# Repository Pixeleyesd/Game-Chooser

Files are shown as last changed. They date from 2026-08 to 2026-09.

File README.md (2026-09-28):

# Game-Chooser

Game-Chooser is a piece of hardware that chooses games for you, using random functions, with a configuration menu for you to confirm which devices you have, so it can decide for you.

## Why did I make this?

I made this to introduce me to ESP32s, as well as being a cool piece of hardware I would use in my every day life. I have consulted a few of my friends about whether they would use something like this, and 6 out of 8 of them said they would also use this. It helps with indecision when deciding which games to play, as well as taking one more decision off the end user.

## Case

Designed with OnShape

### Securing the OLED and Rotary Encoder
The Game Chooser is assembled with exclusively 2mm screws, using nuts on the back side of the OLED and the Rotary Encoder. In assembly you secure these on first, as it will be difficult to access these later.

### Securing the ESP32 to the bottom of the case

The holes under the ESP32 (on the right) will be slightly smaller than 2mm due to print tolerance, therefore allowing the 2mm screw to hold itself using the plastic of the case alone. Secure the ESP32 using the shorter M2 screws, or with nuts between a longer M2 screw and the ESP32.

### Securing the batteries

The battery will be a very tight fit, with the wire end of the AA holder pointing towards the ESP32. Slide in the battery case between the ESP32 pins that stick up, pushing it in the ESP32 direction while pushing it into the case. Once this is done you should have everything inside the case, just push the remaining wires into the case.

### Securing the back panel

The back panel screws will be slightly smaller than 2mm due to print tolerance, therefore allowing the 2mm screw to hold itself using the plastic of the case (and the back panel). Simply screw almost any M2 screw with a long enough length to grip both the back panel and the main body of the case in each of the screw holes. You will need to use reasonable force to do so, you can increase the size of the holes using a drill bit with a diameter of 2mm or less, make sure not to expand it too much otherwise the screw will not grip the plastic properly. Only expand the holes if you have to. If you have a good 3D printer this should not be necessary.

## Firmware

The firmware is written in C++.

Simply flash the .cpp file I have included in the firmware folder using PlatformIO or Arduino IDE. If using either of these, you can check platformio.ini for any of the details not explained here. The board is simply a generic ESP32 Development Board, I have included the libraries you need to install below.

### Required Libraries

igorantolic/Ai Esp32 Rotary Encoder@^1.7
adafruit/Adafruit SSD1306@^2.5.17
adafruit/Adafruit GFX Library@^1.12.6

## Assembly

#### PLEASE NOTE: there may not be enough GND and 3V3 pins for all of the components, you may need to solder a few wires together in order for all components to have GND and power.

Bill of Materials (BOM):

### My 3D printed case
Provided in .STEP format in this repo. Includes the Rotary Encoder cap, body of the case, and back panel.

### Screws
1x M2 Flat Head Screw Set, view an example [here](https://www.amazon.com/dp/B0DHZSPYHH?lv=shuf&channelId=500&plpRedirect=mhFallback)

### Rotary Encoder
1x Rotary encoder HW-040, uses 3V3

### OLED Display
1x 128x64 OLED (GM009605v4.3), uses 5V or 3.3V power, monochrome

### ESP32
1x Generic ESP32 DevKit, 5V OR 3.3V power required.

### Power Supply (AA Batteries)
2x AA Batteries

1x AA x2 Double Side Battery Holder, view an example [here](https://www.ebay.com/itm/254646729123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)

#### PLEASE NOTE: if you are using a 3V or 3.3V battery, plug the battery into the 3V3 pin and plug all components and are plugged into VIN in the diagram into the 3V3 pin instead.

This circuit requires a 5V, 3V or 3.3V power source for the device and all components to function properly. I am currently using a USB-C cable for development and AA batteries for the final circuit, however you can use any 5V, 3.3V or 3V battery. For instance, you can also use a 3V pair of AA batteries wired in series (as shown in the example) or any other power source. The choice is yours!

Please refer to the circuit diagram for assistance in assembling the circuit.

## Breadboard Collapsed Example (No battery)
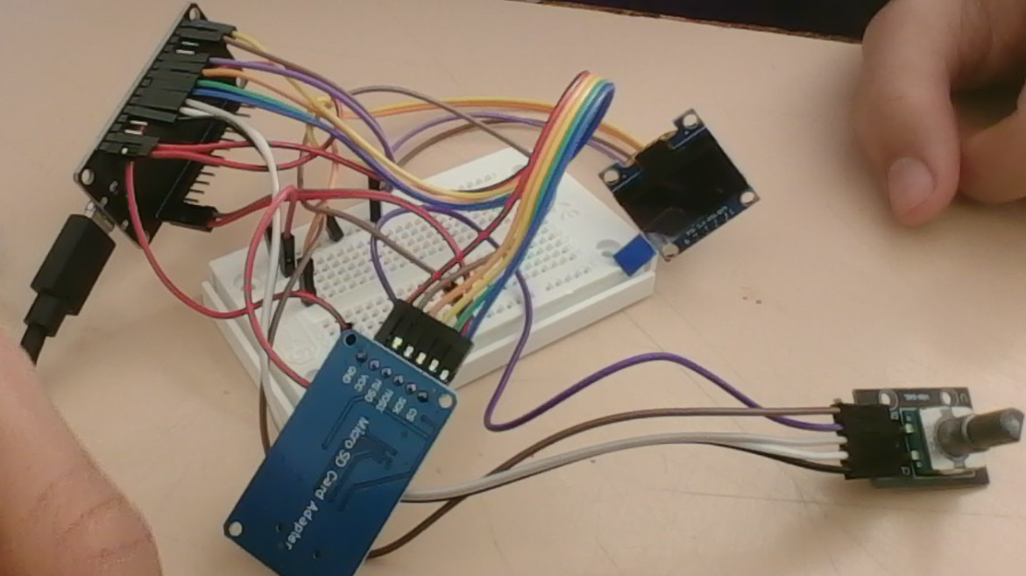
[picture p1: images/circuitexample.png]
breadboardexample


## Constructed Circuit (With battery)

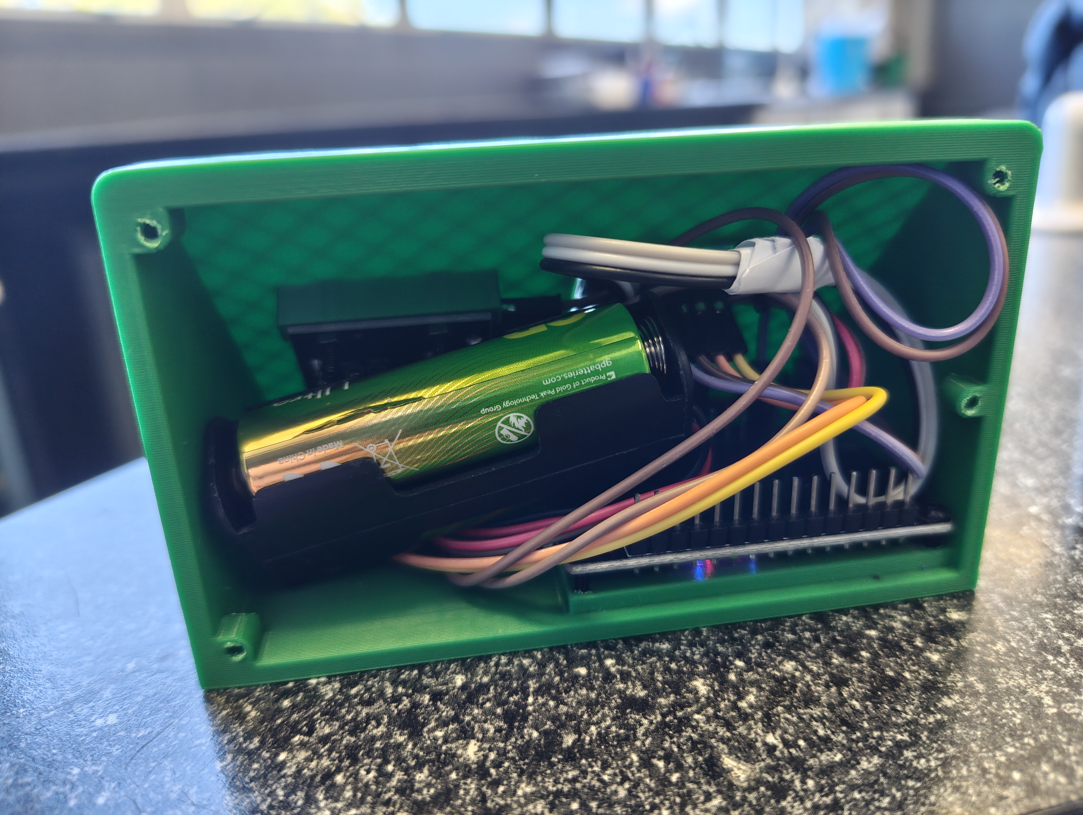
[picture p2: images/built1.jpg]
builtcircuit1


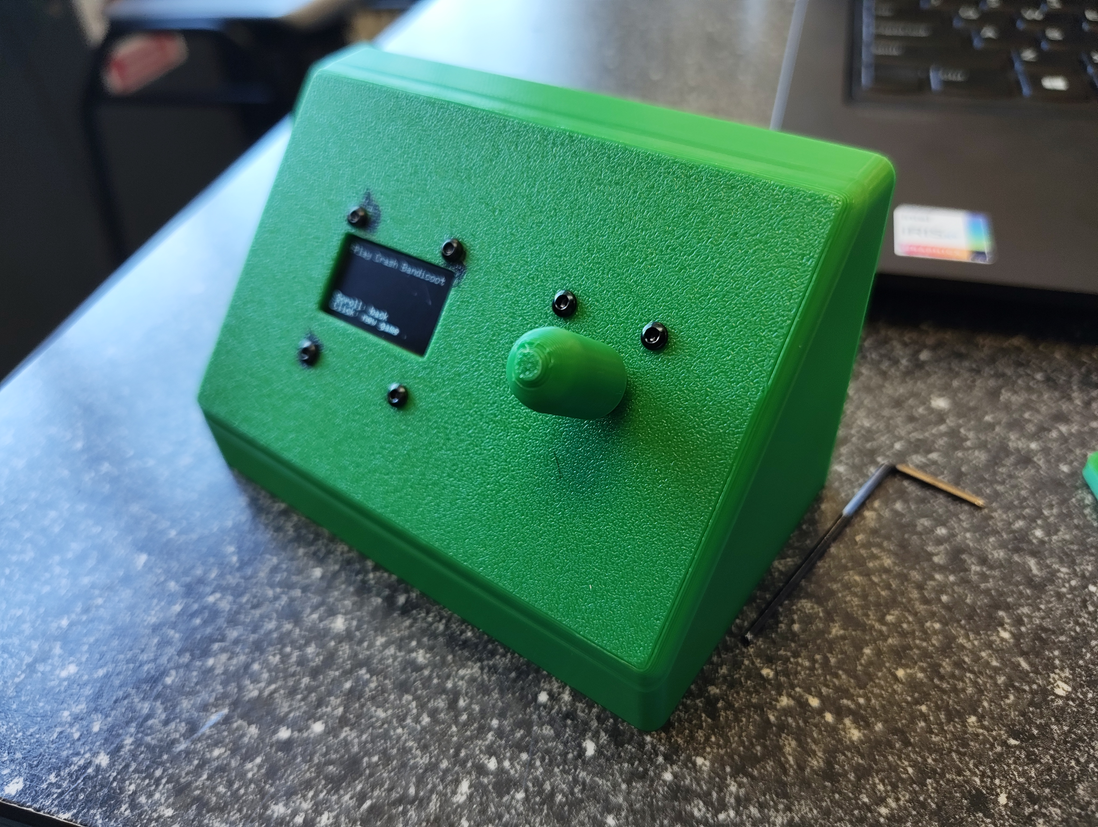
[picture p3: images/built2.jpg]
builtcircuit2


## Circuit Diagram

NOTE: I did not end up using the MicroSD Card reader.

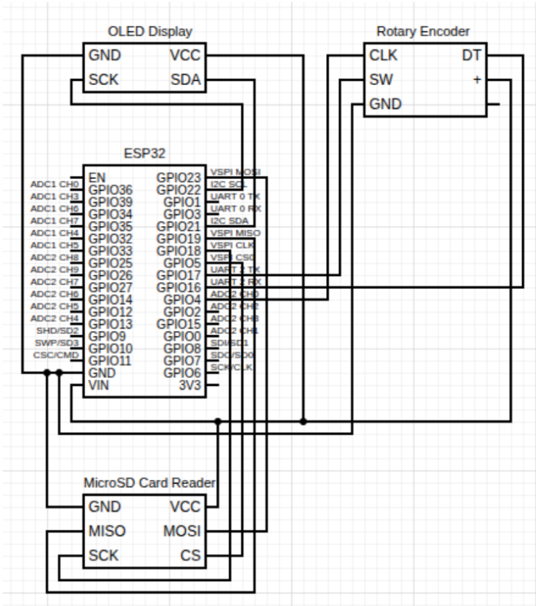
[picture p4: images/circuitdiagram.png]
circuitdiagram


## Relevant Implications
### Usability
Usability is critical because the device relies entirely on a minimal user interface. It consists of a single rotary encoder with a push button and a small 128x64 pixel monochrome OLED display. Without thoughtful interaction design, navigating nested menus on a tiny screen could quickly become frustrating.

How it is addressed in the design:

Visual Ownership Markers: Devices already added to the user's collection are dynamically tagged with an asterisk (*) in the menu rendering (renderMenu), giving instant feedback on system state.

Smart Text Wrapping: Full game titles (like "The Legend of Zelda: Tears of the Kingdom") easily exceed the display's 21-column width. The custom printWrapped() function breaks lines at word spaces rather than cutting words off mid-character.

Persistent Screen Navigation Hints: Dedicated bottom rows show contextual control prompts (e.g., "Scroll: adjust", "Click: start"), eliminating user guesswork.

Rotary Boundaries and Acceleration: Using rotaryEncoder.setBoundaries() prevents index overflow errors, while encoder acceleration ensures smooth scrolling through long lists like the 15 Nintendo models.
### Intellectual Property & Legal
Intellectual Property (IP) is a major consideration because the code explicitly hardcodes trademarked brand names (Playstation, Xbox, Nintendo), hardware model names (PS5, Switch 2, Xbox Series X), and published game titles (Final Fantasy VII, Halo, Pokémon).

How it is addressed in the design:
Personal, Non-Commercial Scope: The software operates entirely locally on an embedded micro-controller as a personal hobbyist utility. It does not distribute copyrighted assets, code, ROMs, artwork, or audio files. It only references textual names.

Fair Use / Nominal Use: Referring to brand names strictly to identify physical consoles and games in a user's personal collection falls under nominal fair use.

Zero Cloud Dependence: The device operates offline without scraping trademarked metadata or connecting to proprietary APIs, avoiding potential terms-of-service violations or network-based trademark claims.
### Functionality 
Functionality dictates whether the device performs reliably within hardware constraints. The ESP32 micro-controller has limited display area, specific pin capabilities, and power constraints, requiring careful code structure to prevent crashes, frozen screens, or inaccurate timer behavior.

How it is addressed in the design:
Non-Blocking Power Management: The sleepScreenIfIdle() function turns off the OLED display after 5 minutes of inactivity (SCREEN_TIMEOUT_MS) to save power and prevent OLED screen burn-in.

Wake-Up Input Protection: The wakeScreenIfAsleep() function intercepts the first button press or rotation after sleep to turn the display back on without accidentally triggering an unintended menu action.

True Hardware Entropy: The randomizer relies on esp_random() to seed the random generator, utilizing internal hardware noise rather than predictable analog read pins to ensure fair game selection.

Shared Memory Game Allocation: Consoles with identical libraries (e.g., PSTV/Vita, Xbox Series S/X) share array pointers (psGameLists, xboxGameLists) to optimize memory footprint.

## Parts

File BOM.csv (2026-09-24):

Item Name | Qty | Price (total) (USD) | Item link | Notes
HW-040 360 Degree Rotary Encoder Module | 1 | $0.58 | https://www.aliexpress.com/i/4001027735982.html
128X64 0.96 inch OLED Module | 1 | $1.06 | https://www.aliexpress.com/i/32805708464.html
ELEGOO ESP-32 Dev Board | 1 | $16.99 | https://www.amazon.com/dp/B0D8T53CQ5?ref=clp_cat_related_p_0&currency=USD | This is a 3 pack of the correct ESP32, I couldn't find them in single packs.
AA x2 Double Side Battery Holder | 1 | $3.40 | https://www.ebay.com/itm/254646729123?chn=ps&var=554695432330&google_free_listing_action=view_item | This is for people who want a similar battery setup to mine
AA Batteries x2 | 1 | $4.25 | https://www.amazon.com/MAX-Alkaline-Batteries-Pack-Battery/dp/B00000DM99
M2 Hex Flat Head Screw Set | 1 | $15.01 | https://www.amazon.com/dp/B0DHZSPYHH?lv=shuf&channelId=500&plpRedirect=mhFallback | This is a set of the correct type of screws.
Total Price (USD): | $41.29

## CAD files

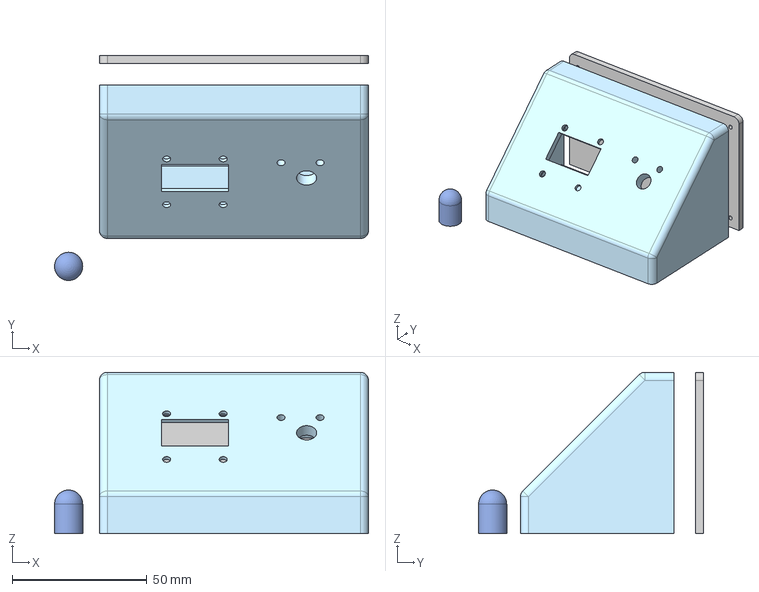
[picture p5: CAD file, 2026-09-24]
CAD/CAD.step
116.7 x 83.6 x 60.0 mm

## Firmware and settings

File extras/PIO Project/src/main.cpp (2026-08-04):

#include <Arduino.h>
#include <AiEsp32RotaryEncoder.h>
#include <Wire.h>
#include <Adafruit_GFX.h>
#include <Adafruit_SSD1306.h>

#define ROTARY_ENCODER_A_PIN 4
#define ROTARY_ENCODER_B_PIN 16
#define ROTARY_ENCODER_BUTTON_PIN 17
#define ROTARY_ENCODER_VCC_PIN -1
#define ROTARY_ENCODER_STEPS 4
#define POWER_LED_PIN 2

// GM009605 0.96" oled, ssd1306 driver, 128x64
#define OLED_SDA_PIN 21
#define OLED_SCK_PIN 22
#define OLED_WIDTH 128
#define OLED_HEIGHT 64
#define OLED_RESET -1
#define OLED_I2C_ADDR 0x3C

AiEsp32RotaryEncoder rotaryEncoder = AiEsp32RotaryEncoder(
  ROTARY_ENCODER_A_PIN, ROTARY_ENCODER_B_PIN,
  ROTARY_ENCODER_BUTTON_PIN, ROTARY_ENCODER_VCC_PIN,
  ROTARY_ENCODER_STEPS
);

Adafruit_SSD1306 display(OLED_WIDTH, OLED_HEIGHT, &Wire, OLED_RESET);

// 128px wide / 6px per char = 21 cols. 64px tall / 8px per char = 8 rows
const int LCD_COLS = 21;
const int LCD_ROWS = 8;
const int CHAR_W = 6;
const int CHAR_H = 8;

// screen auto off after being idle for this long, to save power
const unsigned long SCREEN_TIMEOUT_MS = 5UL * 60UL * 1000UL; // 5 min
unsigned long lastActivityTime = 0;
bool screenAsleep = false;

void IRAM_ATTR readEncoderISR() { rotaryEncoder.readEncoder_ISR(); }
void IRAM_ATTR readButtonISR()  { rotaryEncoder.readButton_ISR(); }

enum Category { CAT_PLAYSTATION, CAT_XBOX, CAT_NINTENDO, CAT_COMPUTER, CAT_COUNT };

const int PS_COUNT = 8;
const char* psModels[PS_COUNT] = { "PSTV", "PS Vita", "PSP", "PS1", "PS2", "PS3", "PS4", "PS5" };
bool psOwned[PS_COUNT] = { false };

const int XBOX_COUNT = 6;
const char* xboxModels[XBOX_COUNT] = { "OG Xbox", "Xbox 360", "Xbox One S", "Xbox One X", "Xbox Series S", "Xbox Series X" };
bool xboxOwned[XBOX_COUNT] = { false };

const int NINTENDO_COUNT = 15;
const char* nintendoModels[NINTENDO_COUNT] = {
  "NES", "SNES", "N64", "GameCube", "Wii", "Wii U", "Switch", "Switch 2",
  "Game Boy", "Game Boy Color", "GBA", "GBA SP", "DS", "3DS", "Virtual Boy"
};
bool nintendoOwned[NINTENDO_COUNT] = { false };

bool computerOwned = false;

// each console gets its own game list instead of sharing one per brand.
// consoles that genuinely share the exact same library in real life
// (PSTV/Vita, Xbox One S/X, Series S/X) just point at the same array

const int GAMES_PER_MODEL = 8;

const char* nesGames[GAMES_PER_MODEL] = {
  "Super Mario Bros.", "The Legend of Zelda", "Metroid", "Mega Man 2",
  "Duck Hunt", "Castlevania", "Kirby's Adventure", "Contra"
};

const char* snesGames[GAMES_PER_MODEL] = {
  "Super Mario World", "The Legend of Zelda: A Link to the Past", "Super Metroid", "Donkey Kong Country",
  "Chrono Trigger", "Super Mario Kart", "Star Fox", "EarthBound"
};

const char* n64Games[GAMES_PER_MODEL] = {
  "Super Mario 64", "The Legend of Zelda: Ocarina of Time", "GoldenEye 007", "Mario Kart 64",
  "Banjo-Kazooie", "Super Smash Bros.", "Star Fox 64", "Paper Mario"
};

const char* gamecubeGames[GAMES_PER_MODEL] = {
  "Super Mario Sunshine", "The Legend of Zelda: The Wind Waker", "Metroid Prime", "Super Smash Bros. Melee",
  "Animal Crossing", "Luigi's Mansion", "Mario Kart: Double Dash!!", "Pikmin"
};

const char* wiiGames[GAMES_PER_MODEL] = {
  "Wii Sports", "Super Mario Galaxy", "The Legend of Zelda: Skyward Sword", "Mario Kart Wii",
  "Super Smash Bros. Brawl", "Xenoblade Chronicles", "Donkey Kong Country Returns", "Metroid Prime 3: Corruption"
};

const char* wiiUGames[GAMES_PER_MODEL] = {
  "Super Mario 3D World", "Mario Kart 8", "Super Smash Bros. for Wii U", "The Legend of Zelda: Breath of the Wild",
  "Bayonetta 2", "Splatoon", "Pikmin 3", "Donkey Kong Country: Tropical Freeze"
};

const char* switchGames[GAMES_PER_MODEL] = {
  "The Legend of Zelda: Tears of the Kingdom", "Super Mario Odyssey", "Super Smash Bros. Ultimate", "Animal Crossing: New Horizons",
  "Splatoon 3", "Super Mario Bros. Wonder", "Metroid Dread", "Pikmin 4"
};

const char* switch2Games[GAMES_PER_MODEL] = {
  "Mario Kart World", "Donkey Kong Bananza", "The Duskbloods", "Splatoon Raiders",
  "Star Fox", "Metroid Prime 4: Beyond", "Fire Emblem: Fortune's Weave", "Pokemon Pokopia"
};

const char* gameboyGames[GAMES_PER_MODEL] = {
  "Pokemon Red and Blue", "The Legend of Zelda: Link's Awakening", "Super Mario Land", "Tetris",
  "Kirby's Dream Land", "Metroid II: Return of Samus", "Donkey Kong", "Wario Land: Super Mario Land 3"
};

const char* gbcGames[GAMES_PER_MODEL] = {
  "Pokemon Gold and Silver", "The Legend of Zelda: Oracle of Seasons", "Super Mario Bros. Deluxe", "Wario Land 3",
  "Pokemon Crystal", "Donkey Kong Country", "Link's Awakening DX", "Pokemon Trading Card Game"
};

const char* gbaGames[GAMES_PER_MODEL] = {
  "Pokemon Ruby and Sapphire", "The Legend of Zelda: The Minish Cap", "Metroid Fusion", "Fire Emblem",
  "Mario Kart: Super Circuit", "Golden Sun", "Metroid: Zero Mission", "Advance Wars"
};

const char* dsGames[GAMES_PER_MODEL] = {
  "New Super Mario Bros.", "Pokemon Diamond and Pearl", "The Legend of Zelda: Phantom Hourglass", "Animal Crossing: Wild World",
  "Mario Kart DS", "Nintendogs", "Professor Layton and the Curious Village", "Kirby: Canvas Curse"
};

const char* threeDSGames[GAMES_PER_MODEL] = {
  "Pokemon X and Y", "The Legend of Zelda: Ocarina of Time 3D", "Super Mario 3D Land", "Animal Crossing: New Leaf",
  "Fire Emblem Awakening", "Luigi's Mansion: Dark Moon", "Kirby: Triple Deluxe", "Mario Kart 7"
};

const char* virtualBoyGames[GAMES_PER_MODEL] = {
  "Mario's Tennis", "Red Alarm", "Galactic Pinball", "Teleroboxer",
  "Virtual Boy Wario Land", "Virtual Fishing", "3D Tetris", "Panic Bomber"
};

// pstv and vita run the same library, so pstv just points at this array too
const char* vitaGames[GAMES_PER_MODEL] = {
  "Persona 4 Golden", "Uncharted: Golden Abyss", "Gravity Rush", "Tearaway",
  "Killzone: Mercenary", "WipEout 2048", "Rayman Legends", "Danganronpa: Trigger Happy Havoc"
};

const char* pspGames[GAMES_PER_MODEL] = {
  "God of War: Chains of Olympus", "Grand Theft Auto: Liberty City Stories", "Crisis Core: Final Fantasy VII", "Patapon",
  "LocoRoco", "Monster Hunter Freedom Unite", "Daxter", "Lumines"
};

const char* ps1Games[GAMES_PER_MODEL] = {
  "Final Fantasy VII", "Metal Gear Solid", "Crash Bandicoot", "Resident Evil 2",
  "Gran Turismo", "Tekken 3", "Castlevania: Symphony of the Night", "Spyro the Dragon"
};

const char* ps2Games[GAMES_PER_MODEL] = {
  "Shadow of the Colossus", "God of War", "Grand Theft Auto: San Andreas", "Metal Gear Solid 2: Sons of Liberty",
  "Final Fantasy X", "Kingdom Hearts", "Ratchet & Clank", "Devil May Cry"
};

const char* ps3Games[GAMES_PER_MODEL] = {
  "The Last of Us", "Uncharted 2: Among Thieves", "God of War III", "Metal Gear Solid 4: Guns of the Patriots",
  "Demon's Souls", "Journey", "LittleBigPlanet", "Heavy Rain"
};

const char* ps4Games[GAMES_PER_MODEL] = {
  "Bloodborne", "Horizon Zero Dawn", "God of War", "Spider-Man",
  "Uncharted 4: A Thief's End", "Ghost of Tsushima", "Persona 5", "Death Stranding"
};

const char* ps5Games[GAMES_PER_MODEL] = {
  "Spider-Man 2", "God of War Ragnarok", "Ratchet & Clank: Rift Apart", "Returnal",
  "Gran Turismo 7", "Final Fantasy VII Rebirth", "Astro Bot", "Stellar Blade"
};

const char* ogXboxGames[GAMES_PER_MODEL] = {
  "Halo: Combat Evolved", "Fable", "Ninja Gaiden", "Jade Empire",
  "Halo 2", "Star Wars: Knights of the Old Republic", "Conker's Bad Fur Day", "Project Gotham Racing"
};

const char* xbox360Games[GAMES_PER_MODEL] = {
  "Halo 3", "Gears of War", "Mass Effect 2", "Fable II",
  "Forza Motorsport 4", "Red Dead Redemption", "Halo: Reach", "Left 4 Dead"
};

// one s and one x run the same games, no exclusives between the two
const char* xboxOneGames[GAMES_PER_MODEL] = {
  "Halo 5: Guardians", "Forza Horizon 3", "Gears of War 4", "Sea of Thieves",
  "Ori and the Blind Forest", "Cuphead", "Sunset Overdrive", "Quantum Break"
};

// series s and series x also run the same games
const char* xboxSeriesGames[GAMES_PER_MODEL] = {
  "Halo Infinite", "Forza Horizon 5", "Gears 5", "Starfield",
  "Hi-Fi Rush", "Psychonauts 2", "Avowed", "Doom Eternal"
};

const char* pcGames[GAMES_PER_MODEL] = {
  "Minecraft", "Roblox", "Portal 2", "Counter-Strike 2",
  "Baldur's Gate 3", "Half-Life 2", "Stardew Valley", "The Witcher 3"
};

// maps each model index within a category to its game list.
// duplicate entries (eg xbox one s and x both pointing at xboxOneGames) are intentional
const char** psGameLists[PS_COUNT]       = { vitaGames, vitaGames, pspGames, ps1Games, ps2Games, ps3Games, ps4Games, ps5Games };
const char** xboxGameLists[XBOX_COUNT]   = { ogXboxGames, xbox360Games, xboxOneGames, xboxOneGames, xboxSeriesGames, xboxSeriesGames };
const char** nintendoGameLists[NINTENDO_COUNT] = {
  nesGames, snesGames, n64Games, gamecubeGames, wiiGames, wiiUGames, switchGames, switch2Games,
  gameboyGames, gbcGames, gbaGames, gbaGames, dsGames, threeDSGames, virtualBoyGames
};

void renderMenu(const char* items[], int itemCount, int selectedIndex, int scrollOffset, bool* ownedFlags,
                const char* title = nullptr, const char* hint0 = nullptr, const char* hint1 = nullptr);
int  selectFromMenu(const char* items[], int itemCount, bool* ownedFlags,
                     const char* title = nullptr, const char* hint0 = nullptr, const char* hint1 = nullptr);
void flushEncoderEvents();
void waitForAnyInput();
bool waitForClickOrRotate();
void showMessage(const char* line0, const char* line1, int delayMs);
void showResultAndWait(const char* line0, String line1);
void printWrapped(String full, int maxRows = LCD_ROWS);
void printHint(const char* line0, const char* line1 = nullptr);
bool confirmAreYouSure();

void registerActivity();
void sleepScreenIfIdle();
bool wakeScreenIfAsleep();

int  categoryModelCount(Category cat);
const char** categoryModelNames(Category cat);
bool* categoryOwnedArray(Category cat);
const char* categoryName(Category cat);
const char* modelNameFor(Category cat, int index);
int  countOwnedInCategory(Category cat);
int  countOwnedDevices();
void pickRandomOwnedDevice(Category &catOut, int &modelIndexOut);
const char* pickRandomGameForModel(Category cat, int modelIndex);
void removeAllDevices();

void showWelcomeScreen();
void mainMenu();
void handleGameOption();
void handleDifficultyOption();
void handleDurationOption();
void renderDurationPicker(int minutes);
void renderTimerScreen(unsigned long remainingSeconds, const char* menuItems[], int menuIndex, bool paused);
void runDurationTimer(unsigned long totalSeconds);
void handleConfigOption();
bool configSubmenuPickOne(Category cat);
bool askAddMore();

// power saving stuff

void registerActivity() {
  lastActivityTime = millis();
}

void sleepScreenIfIdle() {
  if (!screenAsleep && millis() - lastActivityTime > SCREEN_TIMEOUT_MS) {
    display.ssd1306_command(SSD1306_DISPLAYOFF);
    screenAsleep = true;
  }
}

// wakes the screen back up if it was off, returns true if it did.
// caller should treat that input as just a wake up, not a real action
bool wakeScreenIfAsleep() {
  if (screenAsleep) {
    display.ssd1306_command(SSD1306_DISPLAYON);
    screenAsleep = false;
    registerActivity();
    return true;
  }
  return false;
}

// draws one or two short guide lines pinned to the bottom rows of the screen,
// eg "Scroll: back" / "Click: new game". call this before display.display()
void printHint(const char* line0, const char* line1) {
  if (line0 != nullptr) {
    display.setCursor(0, (LCD_ROWS - 2) * CHAR_H);
    display.print(line0);
  }
  if (line1 != nullptr) {
    display.setCursor(0, (LCD_ROWS - 1) * CHAR_H);
    display.print(line1);
  }
}

// title draws on row 0 and pushes the list down. hint0/hint1 pin to the
// bottom rows and shrink the list from below, same idea, opposite end
void renderMenu(const char* items[], int itemCount, int selectedIndex, int scrollOffset, bool* ownedFlags,
                const char* title, const char* hint0, const char* hint1) {
  display.clearDisplay();

  int firstRow = 0;
  if (title != nullptr) {
    display.setCursor(0, 0);
    display.print(title);
    firstRow = 1;
  }

  bool hasHint = (hint0 != nullptr || hint1 != nullptr);
  int lastRow = LCD_ROWS - (hasHint ? 2 : 0);

  for (int row = firstRow; row < lastRow; row++) {
    int i = scrollOffset + (row - firstRow);
    if (i >= itemCount) break;

    display.setCursor(0, row * CHAR_H);

    bool isOwned = ownedFlags != nullptr && ownedFlags[i];
    if (i == selectedIndex) {
      display.print(isOwned ? ">*" : "> ");
    } else {
      display.print(isOwned ? " *" : "  ");
    }

    String label = String(items[i]);
    if (label.length() > (unsigned int)(LCD_COLS - 2)) {
      label = label.substring(0, LCD_COLS - 2);
    }
    display.print(label);
  }

  if (hasHint) printHint(hint0, hint1);

  display.display();
}

int selectFromMenu(const char* items[], int itemCount, bool* ownedFlags, const char* title, const char* hint0, const char* hint1) {
  flushEncoderEvents();

  int index = 0;
  int scrollOffset = 0;
  bool hasHint = (hint0 != nullptr || hint1 != nullptr);
  int visibleRows = LCD_ROWS - (title != nullptr ? 1 : 0) - (hasHint ? 2 : 0);

  rotaryEncoder.setBoundaries(0, itemCount - 1, true); // wrap around
  rotaryEncoder.setEncoderValue(0);
  renderMenu(items, itemCount, index, scrollOffset, ownedFlags, title, hint0, hint1);

  while (true) {
    sleepScreenIfIdle();

    bool rotated = rotaryEncoder.encoderChanged();
    bool clicked = rotaryEncoder.isEncoderButtonClicked();

    if (!rotated && !clicked) continue;

    if (wakeScreenIfAsleep()) {
      renderMenu(items, itemCount, index, scrollOffset, ownedFlags, title, hint0, hint1); // just redraw, ignore this input
      continue;
    }

    registerActivity();

    if (rotated) {
      index = (int)rotaryEncoder.readEncoder();

      if (index < scrollOffset) {
        scrollOffset = index;
      } else if (index >= scrollOffset + visibleRows) {
        scrollOffset = index - visibleRows + 1;
      }
      renderMenu(items, itemCount, index, scrollOffset, ownedFlags, title, hint0, hint1);
    }

    if (clicked) {
      return index;
    }
  }
}

void flushEncoderEvents() {
  rotaryEncoder.encoderChanged();
  rotaryEncoder.isEncoderButtonClicked();
}

bool waitForClickOrRotate() {
  flushEncoderEvents();
  while (true) {
    sleepScreenIfIdle();

    bool clicked = rotaryEncoder.isEncoderButtonClicked();
    bool rotated = rotaryEncoder.encoderChanged();

    if (!clicked && !rotated) continue;

    if (wakeScreenIfAsleep()) continue; // just a wake up, not a real input

    registerActivity();

    if (clicked) return true;
    if (rotated) return false;
  }
}

void waitForAnyInput() {
  waitForClickOrRotate();
}

void showMessage(const char* line0, const char* line1, int delayMs) {
  display.clearDisplay();
  display.setCursor(0, 0);
  display.print(line0);
  if (line1 != nullptr && strlen(line1) > 0) {
    display.setCursor(0, CHAR_H);
    display.print(line1);
  }
  display.display();
  if (delayMs > 0) delay(delayMs);
}

void showResultAndWait(const char* line0, String line1) {
  display.clearDisplay();
  display.setCursor(0, 0);
  display.print(line0);
  display.setCursor(0, CHAR_H);
  display.print(line1);
  printHint("Click or scroll", "to continue");
  display.display();
  waitForAnyInput();
}

// word wraps across up to maxRows rows, since full game titles can run long.
// leave maxRows smaller than LCD_ROWS if you're also drawing a hint underneath
void printWrapped(String full, int maxRows) {
  int row = 0;
  int start = 0;
  int len = full.length();

  while (start < len && row < maxRows) {
    int remaining = len - start;
    int chunkLen = min(remaining, LCD_COLS);

    int breakAt = -1;
    if (remaining > LCD_COLS) {
      // find the last space inside this chunk so we don't cut a word in half
      for (int i = chunkLen; i > 0; i--) {
        if (full.charAt(start + i - 1) == ' ') {
          breakAt = i;
          break;
        }
      }
    }
    if (breakAt == -1) breakAt = chunkLen;

    display.setCursor(0, row * CHAR_H);
    display.print(full.substring(start, start + breakAt));

    start += breakAt;
    while (start < len && full.charAt(start) == ' ') start++; // skip the space we broke on
    row++;
  }
}

// generic yes/no confirm dialog, used by the reset and close buttons in the timer
bool confirmAreYouSure() {
  const char* items[] = { "Yes", "No" };
  int choice = selectFromMenu(items, 2, nullptr, "Are you sure?", "Scroll: choose", "Click: confirm");
  return choice == 0;
}

int categoryModelCount(Category cat) {
  switch (cat) {
    case CAT_PLAYSTATION: return PS_COUNT;
    case CAT_XBOX:         return XBOX_COUNT;
    case CAT_NINTENDO:     return NINTENDO_COUNT;
    default:               return 0; // Computer has no sub-models
  }
}

const char** categoryModelNames(Category cat) {
  switch (cat) {
    case CAT_PLAYSTATION: return psModels;
    case CAT_XBOX:         return xboxModels;
    case CAT_NINTENDO:     return nintendoModels;
    default:               return nullptr;
  }
}

bool* categoryOwnedArray(Category cat) {
  switch (cat) {
    case CAT_PLAYSTATION: return psOwned;
    case CAT_XBOX:         return xboxOwned;
    case CAT_NINTENDO:     return nintendoOwned;
    default:               return nullptr;
  }
}

const char* categoryName(Category cat) {
  switch (cat) {
    case CAT_PLAYSTATION: return "Playstation";
    case CAT_XBOX:         return "Xbox";
    case CAT_NINTENDO:     return "Nintendo";
    case CAT_COMPUTER:     return "Computer";
    default:               return "";
  }
}

const char* modelNameFor(Category cat, int index) {
  if (cat == CAT_COMPUTER) return "Computer";
  return categoryModelNames(cat)[index];
}

int countOwnedInCategory(Category cat) {
  if (cat == CAT_COMPUTER) return computerOwned ? 1 : 0;

  int n = categoryModelCount(cat);
  bool* arr = categoryOwnedArray(cat);
  int c = 0;
  for (int i = 0; i < n; i++) {
    if (arr[i]) c++;
  }
  return c;
}

int countOwnedDevices() {
  int total = 0;
  for (int c = 0; c < CAT_COUNT; c++) {
    total += countOwnedInCategory((Category)c);
  }
  return total;
}

void pickRandomOwnedDevice(Category &catOut, int &modelIndexOut) {
  Category available[CAT_COUNT];
  int availCount = 0;

  for (int c = 0; c < CAT_COUNT; c++) {
    if (countOwnedInCategory((Category)c) > 0) {
      available[availCount++] = (Category)c;
    }
  }

  Category chosenCat = available[random(0, availCount)];
  catOut = chosenCat;

  if (chosenCat == CAT_COMPUTER) {
    modelIndexOut = -1;
    return;
  }

  int n = categoryModelCount(chosenCat);
  bool* arr = categoryOwnedArray(chosenCat);

  int ownedIndices[NINTENDO_COUNT]; // large enough for the biggest category
  int ownedCount = 0;
  for (int i = 0; i < n; i++) {
    if (arr[i]) ownedIndices[ownedCount++] = i;
  }

  modelIndexOut = ownedIndices[random(0, ownedCount)];
}

// picks a game for the exact console model, not just the brand
const char* pickRandomGameForModel(Category cat, int modelIndex) {
  const char** list;

  switch (cat) {
    case CAT_PLAYSTATION: list = psGameLists[modelIndex]; break;
    case CAT_XBOX:         list = xboxGameLists[modelIndex]; break;
    case CAT_NINTENDO:     list = nintendoGameLists[modelIndex]; break;
    case CAT_COMPUTER:     list = pcGames; break;
    default:               return "";
  }

  int idx = random(0, GAMES_PER_MODEL);
  return list[idx];
}

void removeAllDevices() {
  for (int i = 0; i < PS_COUNT; i++) psOwned[i] = false;
  for (int i = 0; i < XBOX_COUNT; i++) xboxOwned[i] = false;
  for (int i = 0; i < NINTENDO_COUNT; i++) nintendoOwned[i] = false;
  computerOwned = false;
}


// switched on, welcome screen, turn on power led
void showWelcomeScreen() {
  display.clearDisplay();
  display.setCursor(0, 0);
  display.print("Game randomiser");
  display.setCursor(0, CHAR_H);
  display.print("Input to start");
  display.display();
  waitForAnyInput();
}

// "input for start randomly choosing: option 1: game, option 2: difficulty,
//  option 3: playing duration, option 4: config"
void mainMenu() {
  const char* items[] = { "Pick a Game", "Difficulty", "Play Duration", "Config" };
  int choice = selectFromMenu(items, 4, nullptr, nullptr, "Scroll: select", "Click: choose");

  switch (choice) {
    case 0: handleGameOption();       break;
    case 1: handleDifficultyOption(); break;
    case 2: handleDurationOption();   break;
    case 3: handleConfigOption();     break;
  }
}

void handleGameOption() {
  if (countOwnedDevices() == 0) {
    showMessage("Add devices in", "option 4: Config", 2000);
    return;
  }

  Category cat;
  int modelIndex;
  pickRandomOwnedDevice(cat, modelIndex);
  const char* model = modelNameFor(cat, modelIndex);

  display.clearDisplay();
  display.setCursor(0, 0);
  display.print(categoryName(cat));
  display.setCursor(0, CHAR_H);
  display.print(model);
  display.display();
  delay(1200);

  display.clearDisplay();
  display.setCursor(0, 0);
  display.print(model);
  display.setCursor(0, CHAR_H);
  display.print("Click to choose!");
  printHint("Scroll: cancel", nullptr);
  display.display();

  if (!waitForClickOrRotate()) {
    return;
  }

  while (true) {
    const char* game = pickRandomGameForModel(cat, modelIndex);
    display.clearDisplay();
    printWrapped(String("Play ") + String(game), LCD_ROWS - 2); // leave the bottom 2 rows for the hint
    printHint("Scroll: back", "Click: new game");
    display.display();

    if (!waitForClickOrRotate()) {
      return;
    }
  }
}

void handleDifficultyOption() {
  const char* difficulties[] = { "Easy", "Medium", "Hard" };
  int idx = (int)random(0, 3);
  showResultAndWait("Difficulty:", String(difficulties[idx]));
}
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
void loop() {
  mainMenu();
}

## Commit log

2026-07-19 fix a few issues
    [main.cpp]
2026-07-19 Rows and Cols are now the correct values
    [main.cpp]
2026-07-20 Fix columns, game selection and add a title thing at the top after a console is selected in config
    [main.cpp]
2026-07-21 edit timer submenu and menu titles
2026-07-29 Add back button to config stuff
2026-09-24 clean up directory further, add CAD and production files, and update README.md
    [CAD.step]
2026-09-24 create bom CSV
    [BOM.csv]
2026-09-24 finalise BOM and finalise README.md
    [BOM.csv]
2026-09-28 Fix formatting of assembly note in README
